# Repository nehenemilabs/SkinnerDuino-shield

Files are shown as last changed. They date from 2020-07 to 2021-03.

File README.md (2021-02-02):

# SkinnerDuino Shield
An arduino UNO shield controller for [operant conditioning chamber (AKA Skinner Box)](https://en.wikipedia.org/wiki/Operant_conditioning_chamber)

Lab A-13 Instituto Neurobiología UNAM

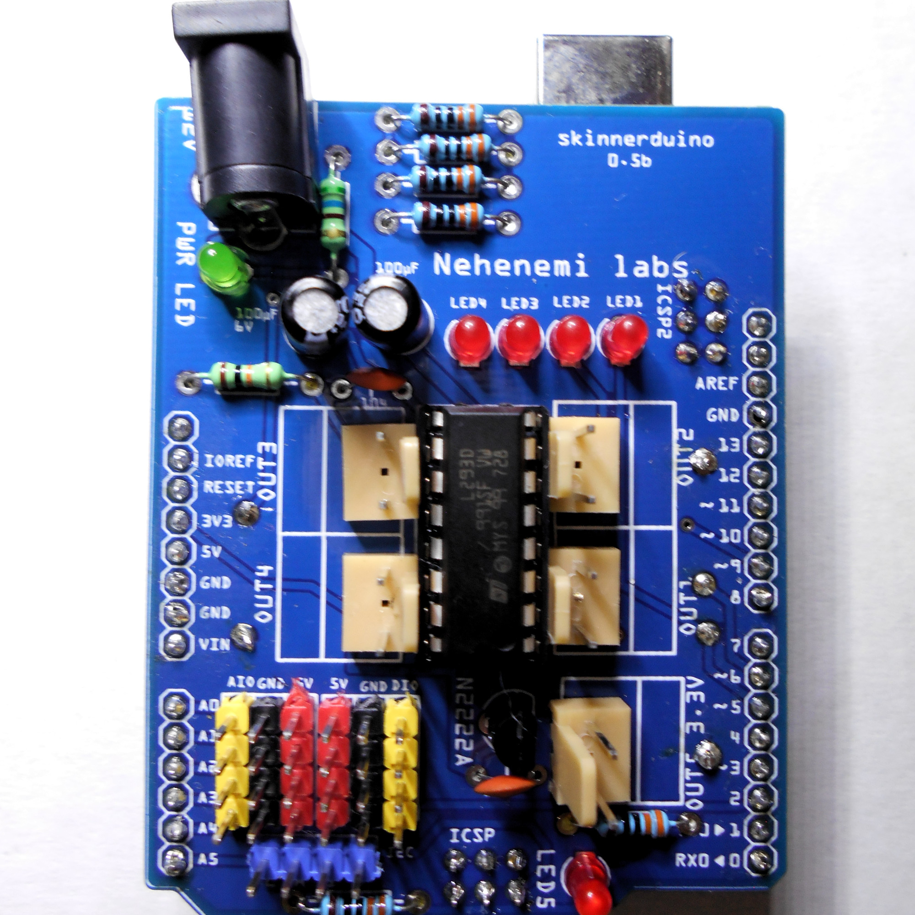
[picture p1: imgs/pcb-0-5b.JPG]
SkinnerDuino


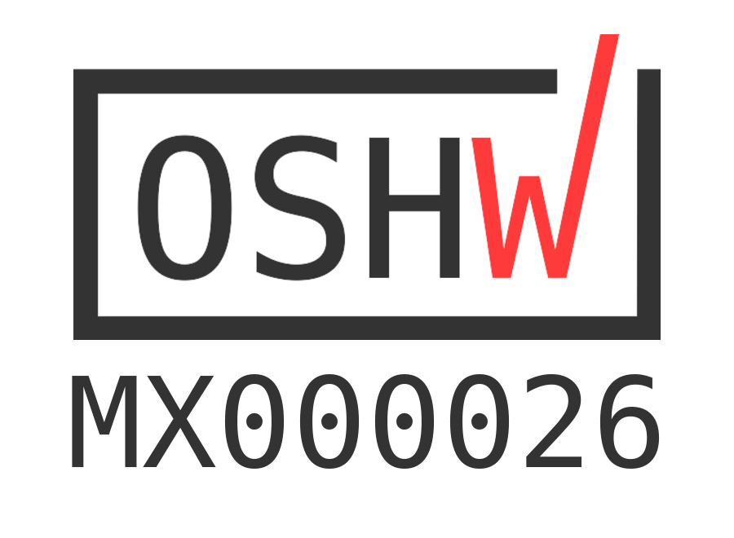
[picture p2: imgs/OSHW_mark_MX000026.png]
OSHWA MX000026


## Features
* Control up to 4 12V PWM DC Motors and 1 3.3V
* Up to 12V
* 1 PWM 3.3V output
* Indicator led for each output
* 1 I2C connector
* 4 Analog inputs,
* 4 Additional IO Ports

# Connections
## Main ports

* PWM Based, 12V
 * OUT1 -> 5
 * OUT2 -> 6
 * OUT3 -> 9
 * OUT4 -> 10

* 3.3V
  * OUT5 -> 3

* Analog IO
  * A0
  * A1
  * A2
  * A3
* Digital IO (DIO)
  * 8
  * 7
  * 4
  * 2
* I2C
  * SCL SDA GND 5V

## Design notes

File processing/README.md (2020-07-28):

This folder contains the software controller examples

# Requirements
## IDE
* Processing >3.3
  *  controlP5 Library
## Firmware
* Arduino
  * Standardfirmata

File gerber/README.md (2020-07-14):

This folder has the gerber ready files both in RS-274X and PDF Format

PDF 

RS-274X

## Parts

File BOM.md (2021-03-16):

# Bill of Materials: 

## Assembly List

<table>

<thead>

<tr>

<th>Label</th>

<th>Part Type</th>

<th>Properties</th>

</tr>

</thead>

<tbody>

<tr>

<td>12V</td>

<td>Power Jack</td>

<td class="props">tipo 5.5mm barrel; paquete power_jack_pth_lock; variante pth_lock</td>

</tr>

<tr>

<td>5V</td>

<td>Generic male header - 4 pins</td>

<td class="props">forma ♂ (male); Tamaño del hoyo 1.0mm,0.508mm; pins 4; paquete THT; espacio entre pines 0.1in (2.54mm); row single</td>

</tr>

<tr>

<td>5V</td>

<td>Generic male header - 4 pins</td>

<td class="props">forma ♂ (male); Tamaño del hoyo 1.0mm,0.508mm; pins 4; paquete THT; espacio entre pines 0.1in (2.54mm); row single</td>

</tr>

<tr>

<td>AIO</td>

<td>Generic male header - 4 pins</td>

<td class="props">forma ♂ (male); Tamaño del hoyo 1.0mm,0.508mm; pins 4; paquete THT; espacio entre pines 0.1in (2.54mm); row single</td>

</tr>

<tr>

<td>Arduino</td>

<td>Arduino Uno (Rev3) - ICSP</td>

<td class="props">tipo Arduino UNO (Rev3) - ICSP</td>

</tr>

<tr>

<td>C3</td>

<td>Capacitor</td>

<td class="props">paquete cap-pth-5mm; variante pth1; número de componente 104</td>

</tr>

<tr>

<td>C4</td>

<td>Capacitor</td>

<td class="props">paquete cap-pth-5mm; variante pth1; número de componente 104</td>

</tr>

<tr>

<td>C5</td>

<td>Electrolytic Capacitor</td>

<td class="props">voltaje 6V; capacitancia 100µF; paquete 100 mil [THT, electrolytic]</td>

</tr>

<tr>

<td>C6</td>

<td>Electrolytic Capacitor</td>

<td class="props">voltaje 16V; capacitancia 100µF; paquete 100 mil [THT, electrolytic]</td>

</tr>

<tr>

<td>DIO</td>

<td>Generic male header - 4 pins</td>

<td class="props">forma ♂ (male); Tamaño del hoyo 1.0mm,0.508mm; pins 4; paquete THT; espacio entre pines 0.1in (2.54mm); row single</td>

</tr>

<tr>

<td>GND</td>

<td>Generic male header - 4 pins</td>

<td class="props">forma ♂ (male); Tamaño del hoyo 1.0mm,0.508mm; pins 4; paquete THT; espacio entre pines 0.1in (2.54mm); row single</td>

</tr>

<tr>

<td>GND</td>

<td>Generic male header - 4 pins</td>

<td class="props">forma ♂ (male); Tamaño del hoyo 1.0mm,0.508mm; pins 4; paquete THT; espacio entre pines 0.1in (2.54mm); row single</td>

</tr>

<tr>

<td>I2C</td>

<td>Generic male header - 4 pins</td>

<td class="props">forma ♂ (male); Tamaño del hoyo 1.0mm,0.508mm; pins 4; paquete THT; espacio entre pines 0.1in (2.54mm); row single</td>

</tr>

<tr>

<td>L293D</td>

<td>L293D</td>

<td class="props">paquete THT; variante L293D</td>

</tr>

<tr>

<td>LED1</td>

<td>Red (633nm) LED</td>

<td class="props">color Red (633nm); paquete 3 mm [THT]; leg yes</td>

</tr>

<tr>

<td>LED2</td>

<td>Red (633nm) LED</td>

<td class="props">color Red (633nm); paquete 3 mm [THT]; leg yes</td>

</tr>

<tr>

<td>LED3</td>

<td>Red (633nm) LED</td>

<td class="props">color Red (633nm); paquete 3 mm [THT]; leg yes</td>

</tr>

<tr>

<td>LED4</td>

<td>Red (633nm) LED</td>

<td class="props">color Red (633nm); paquete 3 mm [THT]; leg yes</td>

</tr>

<tr>

<td>LED5</td>

<td>Red (633nm) LED</td>

<td class="props">color Red (633nm); paquete 3 mm [THT]; leg yes</td>

</tr>

<tr>

<td>N2222A</td>

<td>TRANSISTOR_NPN</td>

<td class="props">paquete to-92; variante to92</td>

</tr>

<tr>

<td>OUT3 3.3V</td>

<td>Camdenboss CTB0158-2</td>

<td class="props">hole size 2.7mm; pins 2; paquete THT; variante 90° 2 connector; espacio entre pines 0.2in (5.08mm); número de componente CTB0158-2</td>

</tr>

<tr>

<td>OUT5</td>

<td>Camdenboss CTB0158-2</td>

<td class="props">hole size 2.7mm; pins 2; paquete THT; variante 90° 2 connector; espacio entre pines 0.2in (5.08mm); número de componente CTB0158-2</td>

</tr>

<tr>

<td>OUT6</td>

<td>Camdenboss CTB0158-2</td>

<td class="props">hole size 2.7mm; pins 2; paquete THT; variante 90° 2 connector; espacio entre pines 0.2in (5.08mm); número de componente CTB0158-2</td>

</tr>

<tr>

<td>OUT9</td>

<td>Camdenboss CTB0158-2</td>

<td class="props">hole size 2.7mm; pins 2; paquete THT; variante 90° 2 connector; espacio entre pines 0.2in (5.08mm); número de componente CTB0158-2</td>

</tr>

<tr>

<td>OUT10</td>

<td>Camdenboss CTB0158-2</td>

<td class="props">hole size 2.7mm; pins 2; paquete THT; variante 90° 2 connector; espacio entre pines 0.2in (5.08mm); número de componente CTB0158-2</td>

</tr>

<tr>

<td>PWR LED</td>

<td>Green (570nm) LED</td>

<td class="props">color Green (570nm); paquete 3 mm [THT]; leg yes</td>

</tr>

<tr>

<td>R1</td>

<td>560Ω Resistor</td>

<td class="props">Resistencia 560Ω; bands 4; paquete THT; tolerancia ±5%; espacio entre pines 400 mil</td>

</tr>

<tr>

<td>R2</td>

<td>1kΩ Resistor</td>

<td class="props">Resistencia 1kΩ; bands 4; paquete THT; tolerancia ±5%; espacio entre pines 400 mil</td>

</tr>

<tr>

<td>R4</td>

<td>330Ω Resistor</td>

<td class="props">Resistencia 330Ω; bands 4; paquete THT; tolerancia ±5%; espacio entre pines 400 mil</td>

</tr>

<tr>

<td>R5</td>

<td>330Ω Resistor</td>

<td class="props">Resistencia 330Ω; bands 4; paquete THT; tolerancia ±5%; espacio entre pines 400 mil</td>

</tr>

<tr>

<td>R6</td>

<td>330Ω Resistor</td>

<td class="props">Resistencia 330Ω; bands 4; paquete THT; tolerancia ±5%; espacio entre pines 400 mil</td>

</tr>

<tr>

<td>R7</td>

<td>330Ω Resistor</td>

<td class="props">Resistencia 330Ω; bands 4; paquete THT; tolerancia ±5%; espacio entre pines 400 mil</td>

</tr>

<tr>

<td>R8</td>

<td>10kΩ Resistor</td>

<td class="props">Resistencia 10kΩ; bands 4; paquete THT; tolerancia ±5%; espacio entre pines 400 mil</td>

</tr>

<tr>

<td>R9</td>

<td>10kΩ Resistor</td>

<td class="props">Resistencia 10kΩ; bands 4; paquete THT; tolerancia ±5%; espacio entre pines 400 mil</td>

</tr>

<tr>

<td>R10</td>

<td>10kΩ Resistor</td>

<td class="props">Resistencia 10kΩ; bands 4; paquete THT; tolerancia ±5%; espacio entre pines 400 mil</td>

</tr>

<tr>

<td>R11</td>

<td>10kΩ Resistor</td>

<td class="props">Resistencia 10kΩ; bands 4; paquete THT; tolerancia ±5%; espacio entre pines 400 mil</td>

</tr>

<tr>

<td>R17</td>

<td>330Ω Resistor</td>

<td class="props">Resistencia 330Ω; bands 4; paquete THT; tolerancia ±5%; espacio entre pines 400 mil</td>

</tr>

</tbody>

</table>

## Shopping List

<table>

<thead>

<tr>

<th>Amount</th>

<th>Part Type</th>

<th>Properties</th>

</tr>

</thead>

<tbody>

<tr>

<td>1</td>

<td>Power Jack</td>

<td class="props">tipo 5.5mm barrel; paquete power_jack_pth_lock; variante pth_lock</td>

</tr>

<tr>

<td>7</td>

<td>Generic male header - 4 pins</td>

<td class="props">forma ♂ (male); Tamaño del hoyo 1.0mm,0.508mm; pins 4; paquete THT; espacio entre pines 0.1in (2.54mm); row single</td>

</tr>

<tr>

<td>1</td>

<td>Arduino Uno (Rev3) - ICSP</td>

<td class="props">tipo Arduino UNO (Rev3) - ICSP</td>

</tr>

<tr>

<td>2</td>

<td>Capacitor</td>

<td class="props">paquete cap-pth-5mm; variante pth1; número de componente 104</td>

</tr>

<tr>

<td>1</td>

<td>Electrolytic Capacitor</td>

<td class="props">voltaje 6V; capacitancia 100µF; paquete 100 mil [THT, electrolytic]</td>

</tr>

<tr>

<td>1</td>

<td>Electrolytic Capacitor</td>

<td class="props">voltaje 16V; capacitancia 100µF; paquete 100 mil [THT, electrolytic]</td>

</tr>

<tr>

<td>1</td>

<td>L293D</td>

<td class="props">paquete THT; variante L293D</td>

</tr>

<tr>

<td>5</td>

<td>Red (633nm) LED</td>

<td class="props">color Red (633nm); paquete 3 mm [THT]; leg yes</td>

</tr>

<tr>

<td>1</td>

<td>TRANSISTOR_NPN</td>

<td class="props">paquete to-92; variante to92</td>

</tr>

<tr>

<td>5</td>

<td>Camdenboss CTB0158-2</td>

<td class="props">hole size 2.7mm; pins 2; paquete THT; variante 90° 2 connector; espacio entre pines 0.2in (5.08mm); número de componente CTB0158-2</td>

</tr>

<tr>

<td>1</td>

<td>Green (570nm) LED</td>

<td class="props">color Green (570nm); paquete 3 mm [THT]; leg yes</td>

</tr>

<tr>

<td>1</td>

<td>560Ω Resistor</td>

<td class="props">Resistencia 560Ω; bands 4; paquete THT; tolerancia ±5%; espacio entre pines 400 mil</td>

</tr>

<tr>

<td>1</td>

<td>1kΩ Resistor</td>

<td class="props">Resistencia 1kΩ; bands 4; paquete THT; tolerancia ±5%; espacio entre pines 400 mil</td>

</tr>

<tr>

<td>5</td>

<td>330Ω Resistor</td>

<td class="props">Resistencia 330Ω; bands 4; paquete THT; tolerancia ±5%; espacio entre pines 400 mil</td>

</tr>

<tr>

<td>4</td>

<td>10kΩ Resistor</td>

<td class="props">Resistencia 10kΩ; bands 4; paquete THT; tolerancia ±5%; espacio entre pines 400 mil</td>

</tr>

</tbody>

</table>

Exported with Fritzing 0.9.4- http://fritzing.org

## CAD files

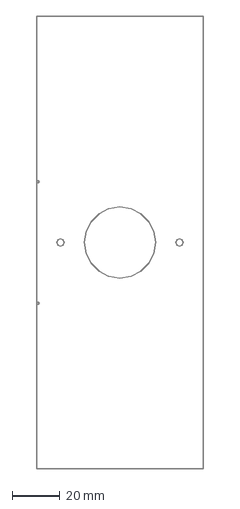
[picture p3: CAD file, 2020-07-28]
case/perilstaltic pump base.dxf
70.0 x 190.0 mm

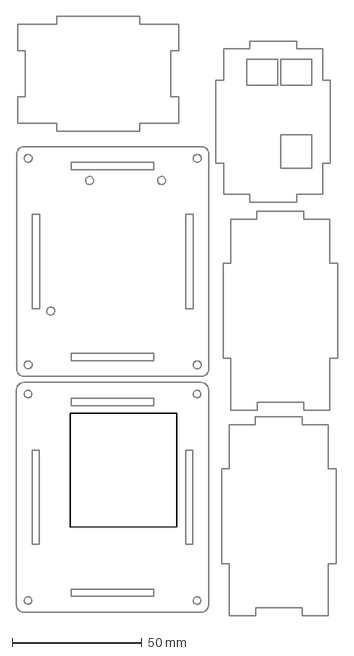
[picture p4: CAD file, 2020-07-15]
case/box.dxf
123.7 x 230.6 mm

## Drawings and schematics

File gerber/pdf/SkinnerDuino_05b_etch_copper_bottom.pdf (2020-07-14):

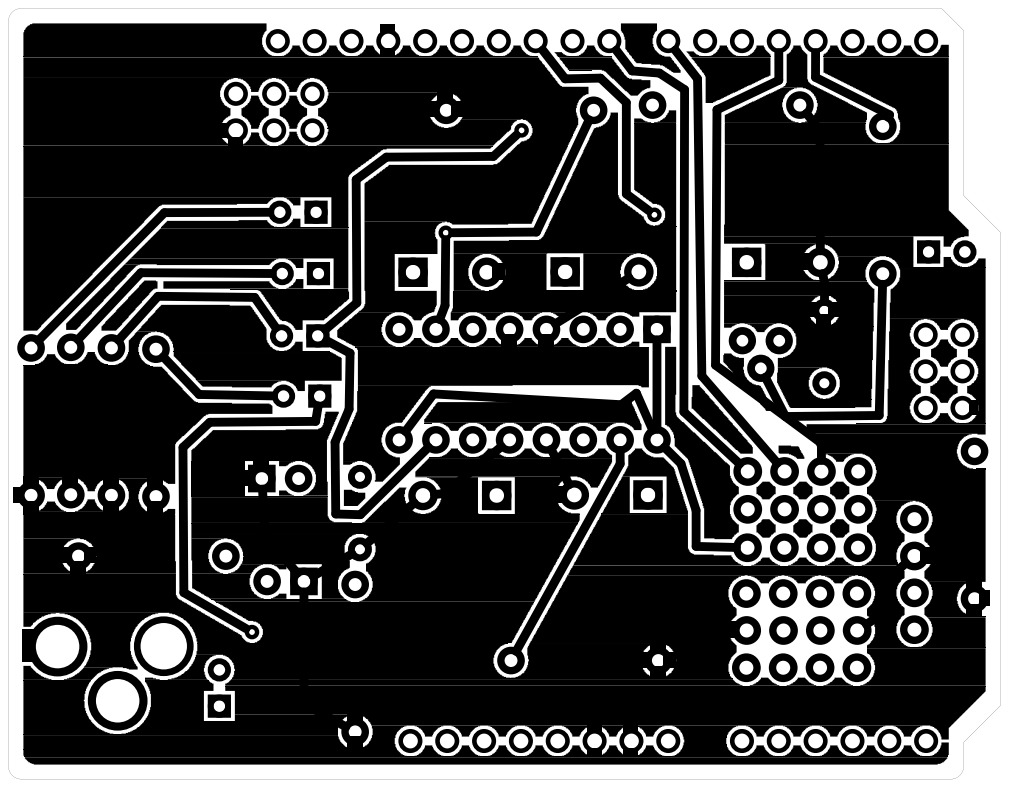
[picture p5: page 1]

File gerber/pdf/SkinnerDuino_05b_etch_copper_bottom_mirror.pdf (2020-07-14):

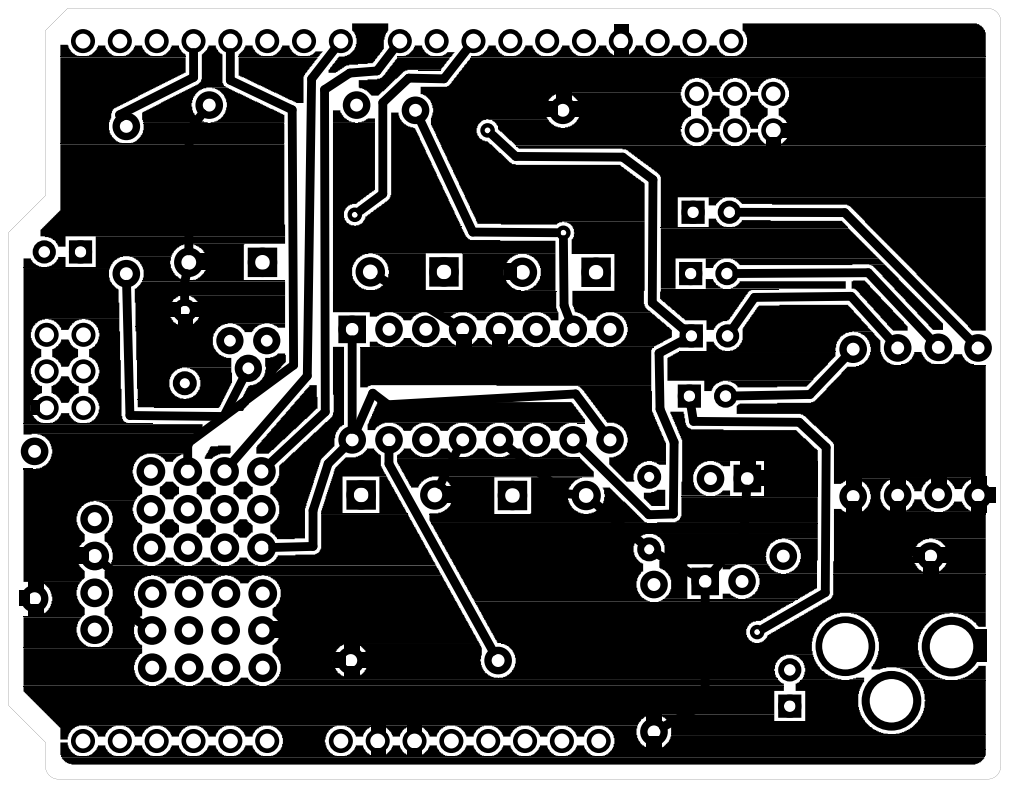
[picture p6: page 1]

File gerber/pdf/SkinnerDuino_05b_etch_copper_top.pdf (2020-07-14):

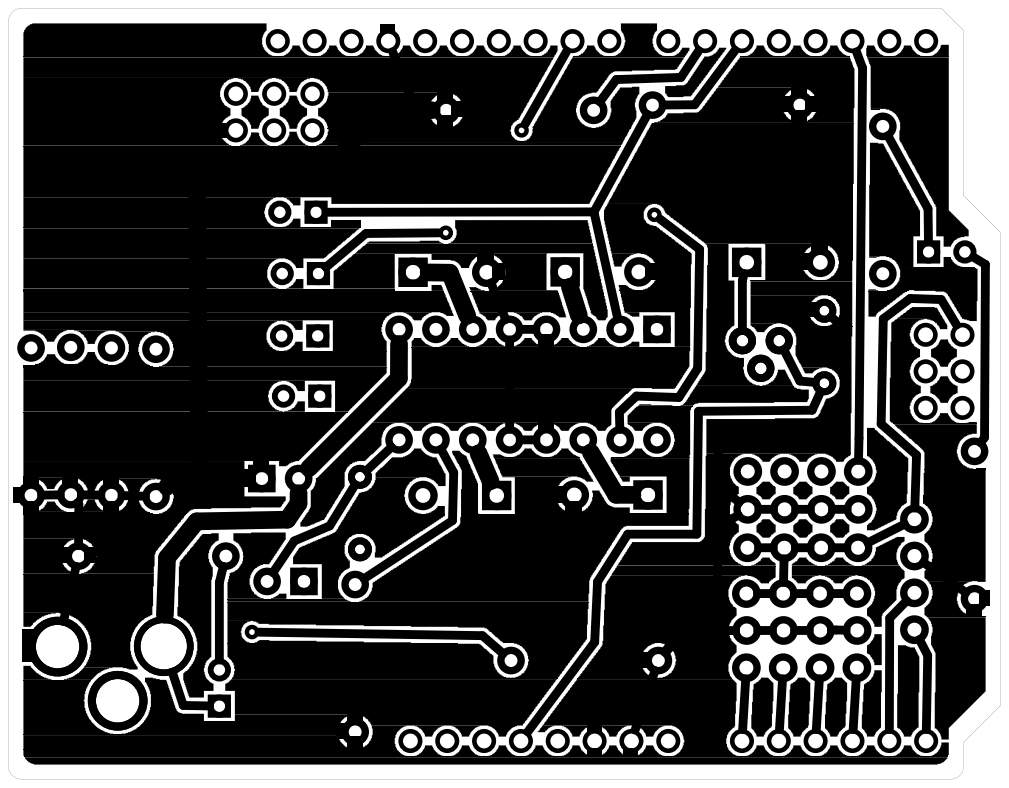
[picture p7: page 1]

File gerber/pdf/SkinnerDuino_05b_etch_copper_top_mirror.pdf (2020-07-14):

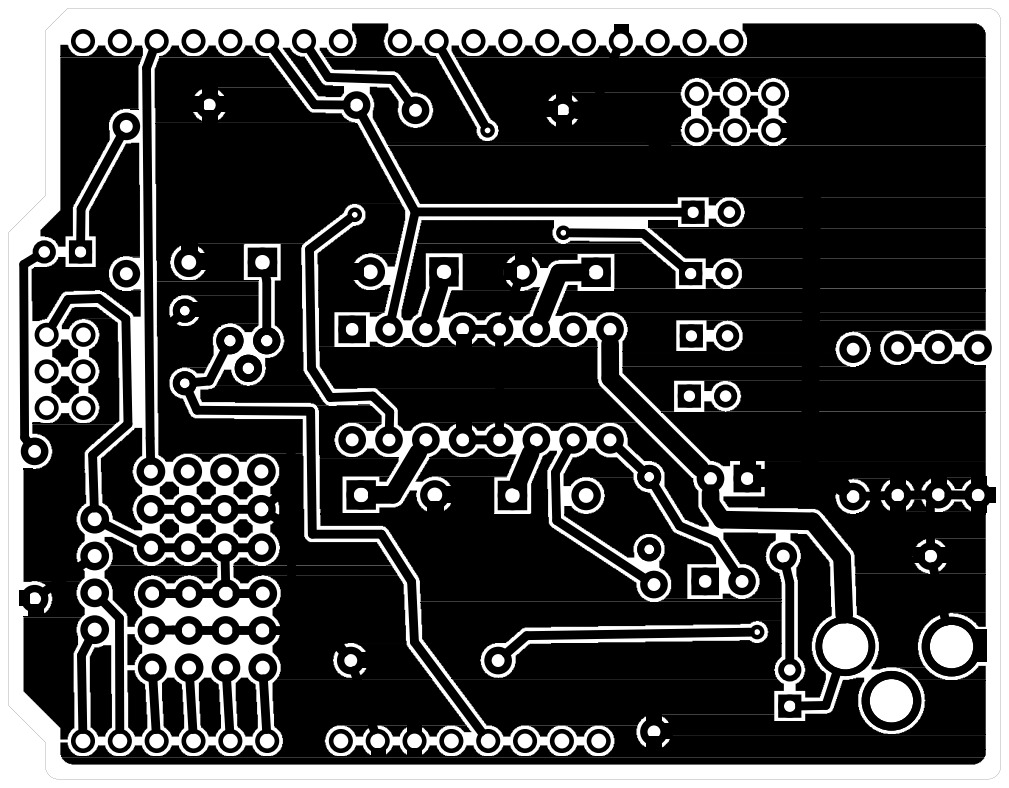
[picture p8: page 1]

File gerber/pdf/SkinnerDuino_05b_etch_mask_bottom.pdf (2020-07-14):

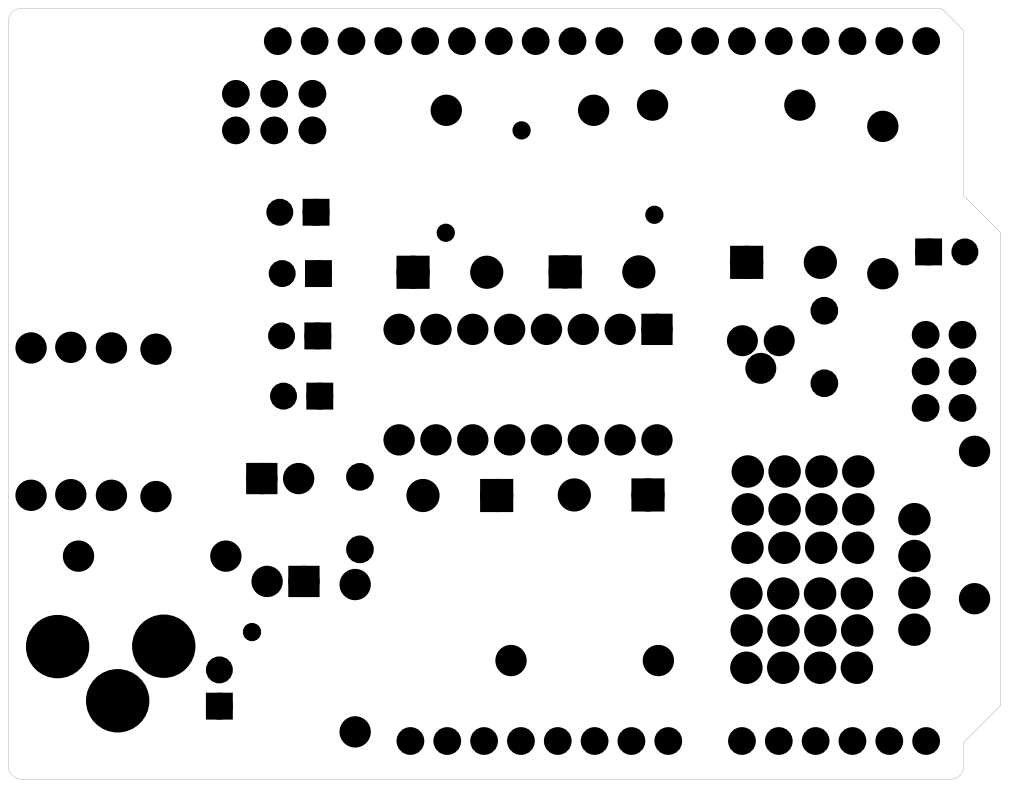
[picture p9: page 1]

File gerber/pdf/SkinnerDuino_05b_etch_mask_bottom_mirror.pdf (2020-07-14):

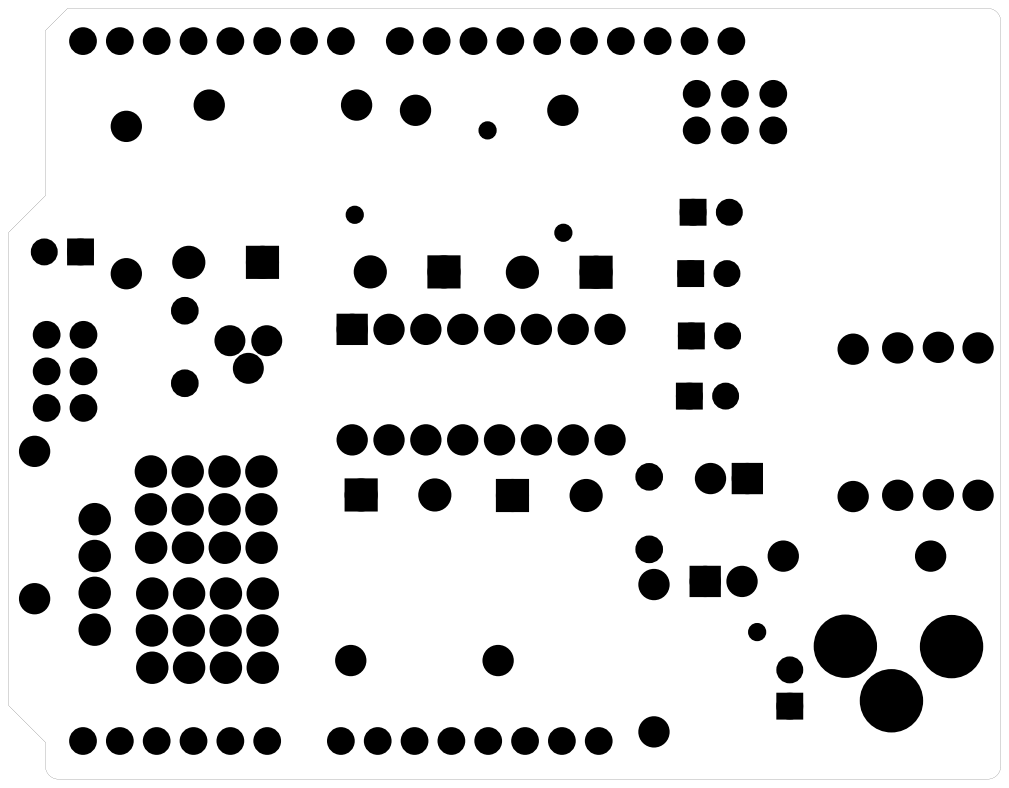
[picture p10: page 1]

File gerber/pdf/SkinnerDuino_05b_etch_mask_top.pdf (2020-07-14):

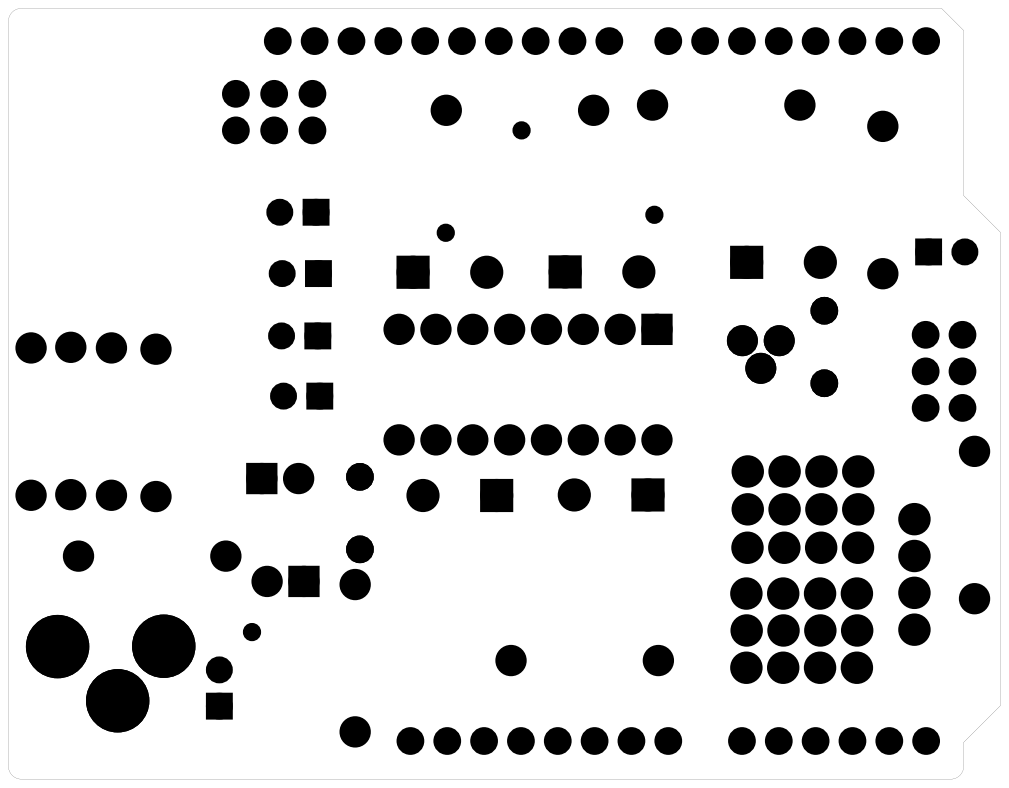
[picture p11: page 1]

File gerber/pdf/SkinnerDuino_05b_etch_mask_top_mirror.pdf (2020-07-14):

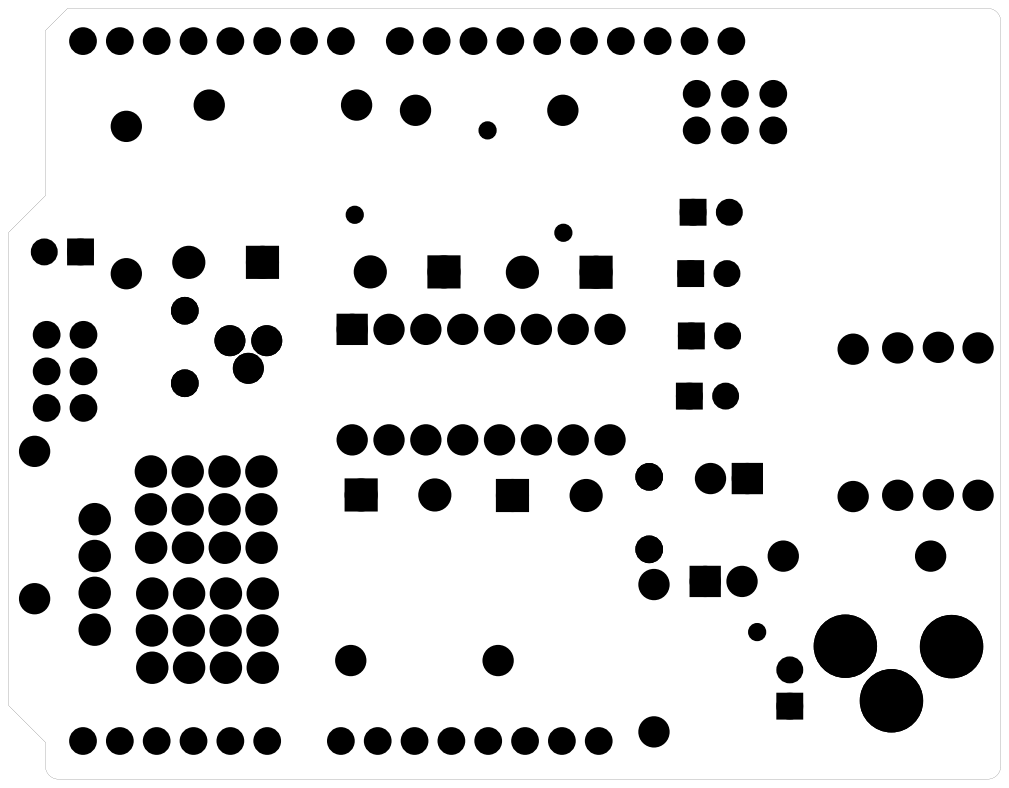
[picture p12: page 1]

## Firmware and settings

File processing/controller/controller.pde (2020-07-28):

import cc.arduino.*;
import org.firmata.*;
import processing.serial.*;
import controlP5.*;
import java.util.*;

int serialPortNumber;
String osName;
int motorL = 5;
int motorR = 6;
int motorV = 3;
int sensorL = 2;
int sensorR = 4;
int timeFeed = 5;

Arduino ardu;
ControlP5 cp5;
Textfield fldFreq1;
Textfield fldFreq2;
Textfield fldTime1;
Textfield fldTime2;
Textfield fldTimeout;
Button btnRun;
Button btnFill;
Button btnLeft;
Button btnRight;

void setup()
{
  println(Arduino.list());
  size(250,100);
  background(0);
  surface.setTitle("Haptic Mice");
  cp5 = new ControlP5(this);
  btnFill = cp5.addButton("fill")
  .setPosition(0,0)
  ;
  fldFreq1 = cp5.addTextfield("freq1")
    .setPosition(110,0)
    .setSize(40,20)
    .setText("0");
  fldFreq2 = cp5.addTextfield("freq2")
    .setPosition(110,40)
    .setSize(40,20)
    .setText("0");
   ;
  btnRun = cp5.addButton("run")
    .setPosition(160,80)
    .setSize(80,20)
    ;
  btnLeft = cp5.addButton("left")
    .setPosition(0,80);
  btnRight = cp5.addButton("right")
    .setPosition(80,80);

    ardu = new Arduino(this,Arduino.list()[0],57600);
    ardu.pinMode(2,Arduino.INPUT);
    ardu.pinMode(4,Arduino.INPUT);
    ardu.pinMode(3,Arduino.OUTPUT);
    ardu.pinMode(5,Arduino.OUTPUT);
    ardu.pinMode(6,Arduino.OUTPUT);
}

void draw()
{
}

public void controlEvent(ControlEvent event)
{
  if (event.getController().getName() == "run")
  {
    println("run");
    println(int(fldFreq1.getText()));
    vibrate(int(fldFreq1.getText()),1);
    delay(500);
    println(int(fldFreq2.getText()));
    vibrate(int(fldFreq2.getText()),1);
    println("end");

  } else if (event.getController().getName() == "fill")
  {
    println("filling");
    ardu.digitalWrite(motorL,Arduino.HIGH);
    ardu.digitalWrite(motorR,Arduino.HIGH);
    delay(9000);
    ardu.digitalWrite(motorR,Arduino.LOW);
    ardu.digitalWrite(motorL,Arduino.LOW);
  } else if (event.getController().getName() == "left")
  {
    feed(motorL);
    println("left");
  } else if (event.getController().getName() == "right")
  {
    feed(motorR);
    println("right");
  }
}

void feed(int motor)
{
  ardu.digitalWrite(motor,Arduino.HIGH);
  delay(timeFeed);
  ardu.digitalWrite(motor,Arduino.LOW);
  delay(10);
  ardu.digitalWrite(motor,Arduino.HIGH);
  delay(timeFeed);
  ardu.digitalWrite(motor,Arduino.LOW);
}

void vibrate(int ifreq,int iduration)
{
  if(ifreq > 0)
  {
    int off_time,duration;
    off_time = (1000/ifreq);
    duration = (ifreq*iduration)-1;
    for (int i = 0; i <= duration; i++)
    {
     ardu.digitalWrite(3,Arduino.HIGH);
     delay(10);
     ardu.digitalWrite(3,Arduino.LOW);
     delay(off_time);
    }
  } else {
    delay(iduration);
  }
}

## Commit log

2020-07-14 Updated documennts and files
    [SkinnerDuino_05b.fzz]
2020-07-14 Added changes
    [SkinnerDuino_05b_contour.gm1, SkinnerDuino_05b_copperBottom.gbl, SkinnerDuino_05b_copperTop.gtl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]
2020-07-15 added case
    [box.dxf]
2020-07-28 added .gitignore
    [perilstaltic pump base.dxf]
2021-03-16 changed resistor to 1 kOhm
    [SkinnerDuino_05b.fzz]
